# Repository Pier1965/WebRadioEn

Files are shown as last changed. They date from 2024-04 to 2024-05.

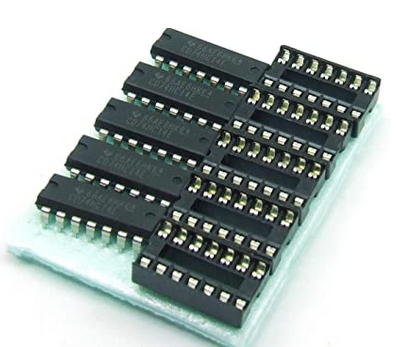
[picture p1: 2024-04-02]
Docs/Bom/img/74HC14.png

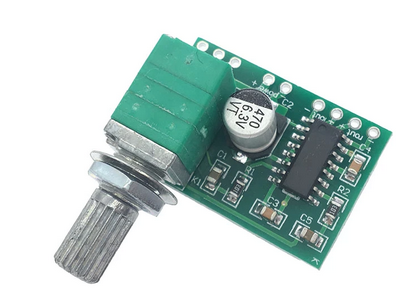
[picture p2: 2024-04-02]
Docs/Bom/img/PAM8432.png

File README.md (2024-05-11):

Esp32 web radio
---------------

This is a esp32 based web radio.
All the hardware requirements, schematics and pinout, can be fount in the Docs subfolders.
All the drawings for a suitable 3D printed case, in openscad format, can be found
in the Docs/drawings directory.

Settings
--------
The following files could/should be altered in order to personalize the compilation
process. This latter can been performed relying on VS code and the Platformio plugin:
- platformio.ini (set the esp32 model);
- include/gpio.h (for different pinout configuration);
- include/define.h (change OLED dimensions and pinout, enable use of NEXTION touch);
- nclude/ir_butt.h (setting the IR remote control);
- include/preproDefine.h (to set debug option);
- include/GlobalVar.h (to set a different ntp server);
- include/GlobalObject.h line 16 (to set the local time zone).

First run
---------
With the working mode switch (clock/radio) in clock position,
at the first start the radio will act as an Access Point with
the name "WebRadioAP". Connect to it and go to the address
192.168.1.4 where SSID and password of the home wifi can be set.
SSID and password can be changed anytime in clock mode pushing
the volumeUp button.

List of radios managing
-----------------------
At the first start a few stations will be available. The list of stations
can be altered by accessing the address of the radio,
readable on the OLED screen by means of a browser.
Stations can be:
- added;
- deleted singularly and in group;
- reordered moving each station in a new position in list;
- swapped in position;
- searched via key word search querying https://www.radio-browser.info/
- the list created can be exported in json format;
- a list can be inported in json format.

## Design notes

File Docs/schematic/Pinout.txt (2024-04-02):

  Wiring:
  ---------------------
  | VS1053  |  ESP32  |
  ---------------------
  |   SCK   |  IO18   |
  |   MISO  |  IO19   |
  |   MOSI  |  IO23   |
  |   XRST  |  EN     |
  |   CS    |  IO5    |
  |   DCS   |  IO0    |
  |   DREQ  |  IO4    |
  |   5V    |  5V     |
  |   GND   |  GND    |
  ---------------------

  ---------------------------
  | JMDO 96C-1 OLED | ESP32 |
  ---------------------------
  | SDA             | 21    |
  | SCL             | 22    |
  | GND             | GND   |
  | 5V              | 5V    |
  ---------------------------

  ---------------------------
  | IR module elegoo | ESP32 |
  ---------------------------
  | G                | GND   |
  | R                | 5V    |
  | Y                | G26   |
  ----------------------------

  ----------------------------
  | Pulsanti         | ESP32  |
  ----------------------------
  | Vol UP           | G32    |
  | Vol Down         | G33    |
  | Next Station     | G13/34 | wroom/wrover - B ttgo
  | Prv Station      | G12    |
  | Radio-Clock Sel  | G36/35 | wroom/wrover - B ttgo
  ----------------------------

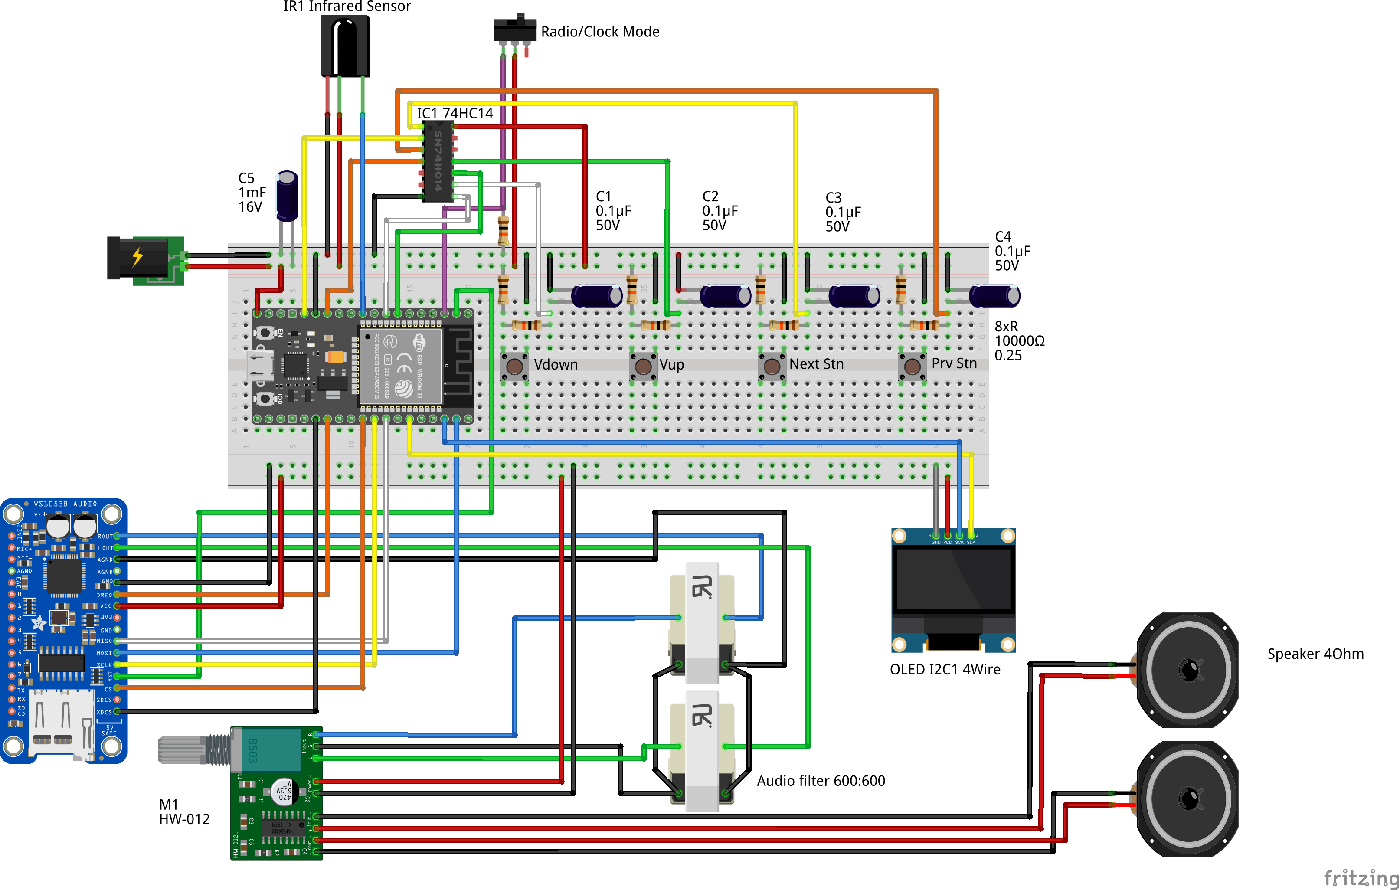
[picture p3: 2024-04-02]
Docs/Bom/img/Schematic.png

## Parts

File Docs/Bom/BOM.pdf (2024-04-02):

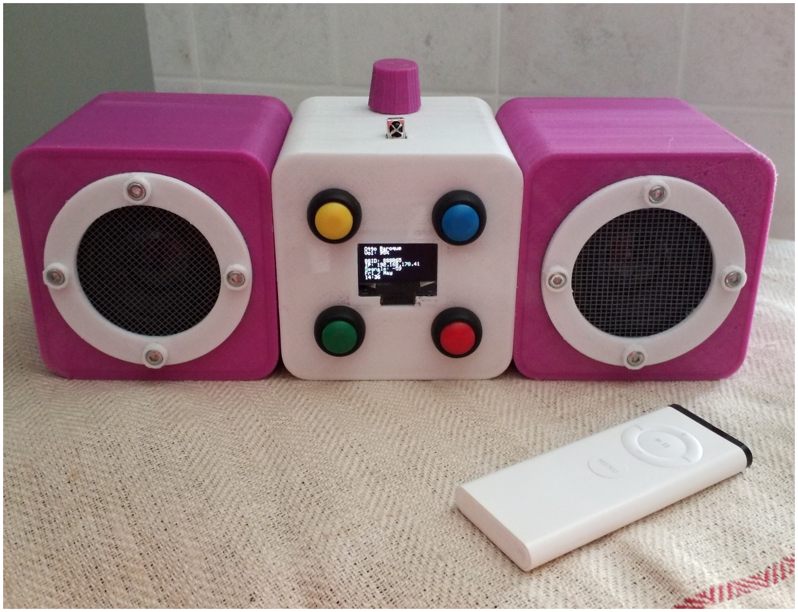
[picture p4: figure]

# N-th Web Radio

# Bill of Materials

Q.ty | Description | Picture | Link

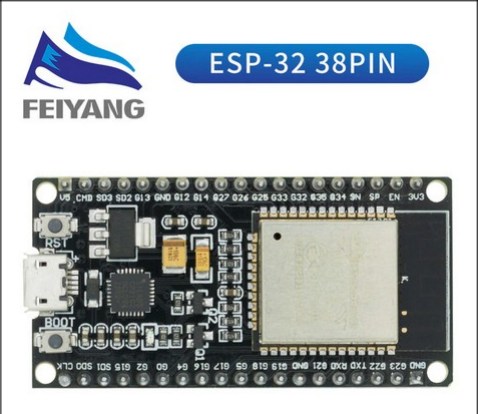
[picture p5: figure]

n.1 | ERP32 Wroom | | ESP32 (https://it.aliexpress.com/item/32864722159.html?spm=a2g0s.9042311.0.0.27424c4dDjW3SZ)

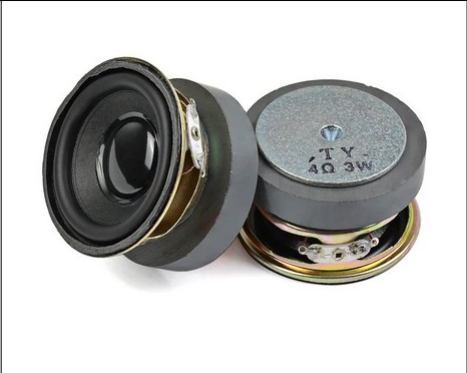
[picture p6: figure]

N.2 | AIYIMA 2 PCS 4ohm 3 W | | Loudspeaker 4Ohm (https://it.aliexpress.com/item/32912123079.html?spm=a2g0s.9042311.0.0.27424c4dL3zYdo)

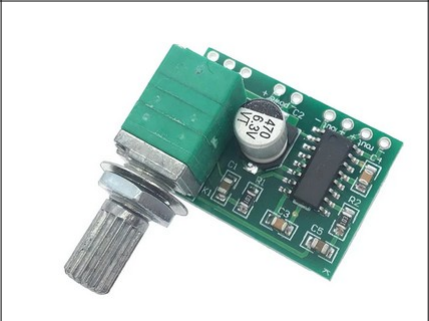
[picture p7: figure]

N.1 | PAM8403 | | Amplifier (https://it.aliexpress.com/item/966217332.html?spm=a2g0s.9042311.0.0.27424c4dr9aevu)

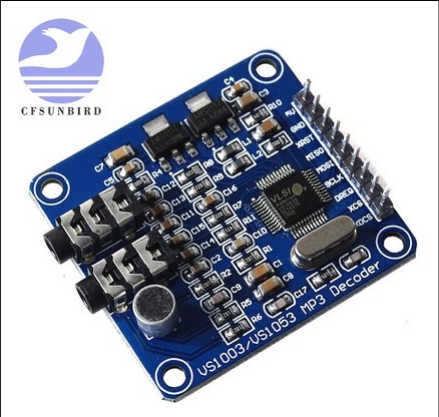
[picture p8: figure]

N.1 | VS1003B VS1053 | | Mp3 chip (https://it.aliexpress.com/item/4001146067436.html?spm=a2g0s.9042311.0.0.27424c4dr9aevu)

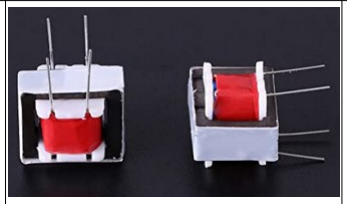
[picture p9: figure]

N.2 | Audio transformer T 1:1 / 600:600 | | Audio filters (https://www.amazon.it/gp/product/B08JCWNKHQ/ref=ppx_yo_dt_b_asin_title_o06_s00?ie=UTF8&psc=1)

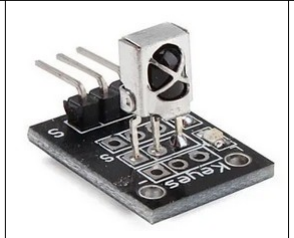
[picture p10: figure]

N.1 | IR Sensor | KY-022 IR (https://it.banggood.com/KY-022-Infrared-IR-Sensor-Receiver-Module-p-916178.html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)

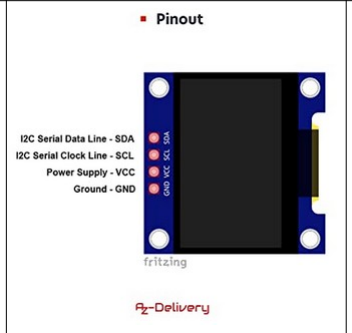
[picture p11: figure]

N.1 | OLED 128x64 4 wire | OLED 1306 (https://www.amazon.it/gp/product/B074N9VLZX/ref=ppx_yo_dt_b_asin_title_o03_s00?ie=UTF8&psc=1)


N.1 | HC74C14 Triggered NOT gate | 74HC14 (https://www.amazon.it/gp/product/B07DT37Y85/ref=ppx_yo_dt_b_asin_title_o07_s00?ie=UTF8&psc=1)


N.1 | Electrolytic capacitor: 1mF x 16V | 1mF Capacitor (https://www.amazon.it/gp/product/B07MNZRBRQ/ref=ppx_yo_dt_b_asin_title_o05_s00?ie=UTF8&psc=1)


N.4 | Electrolytic capacitor: 0.1umF x 16V | 1mF Capacitor (https://www.amazon.it/gp/product/B07MNZRBRQ/ref=ppx_yo_dt_b_asin_title_o05_s00?ie=UTF8&psc=1)


N.9 | Resistor 10KOhm 0.25W | Resistors (https://www.amazon.it/dp/B071Z66XDV?aaxitk=a59ea1286d5f9834aeef6317356b4ac4&hsa_cr_id=2948124570102)


N.4 | Push buttons | Push buttons (https://www.amazon.it/gp/product/B06XCSB9N3/ref=ppx_yo_dt_b_asin_title_o06_s00?ie=UTF8&psc=1)


N.1 | 5.5mm Power supply jack | 5.5 mm Jack (https://hobbyking.com/en_us/2-1mm-5-5mm-dc-chassis-socket-jack-2pc.html?___store=en_us)


N.1 | Switch Radio/Clock mode | Switch (https://www.amazon.it/NATEE-Interruttore-Levetta-Bilanciere-TEN1021/dp/B082B2HCNF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)

# Schematic


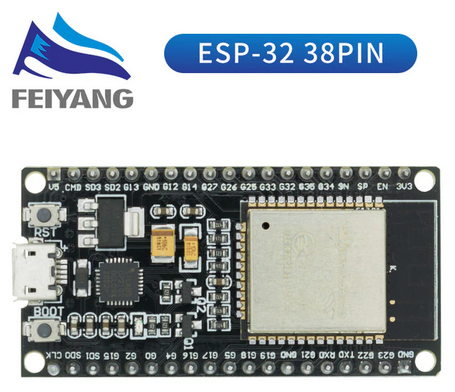
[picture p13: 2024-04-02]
Docs/Bom/img/esp32-wroom.png

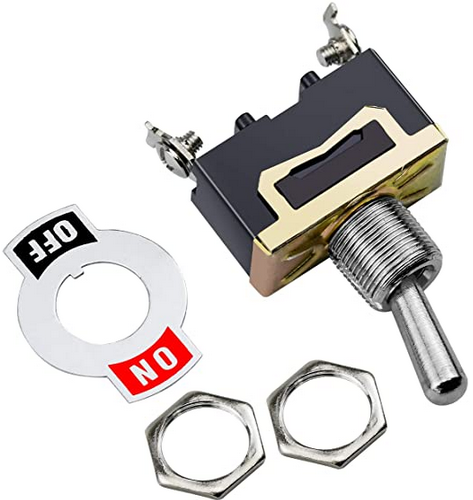
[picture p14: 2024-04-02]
Docs/Bom/img/interruttore.png

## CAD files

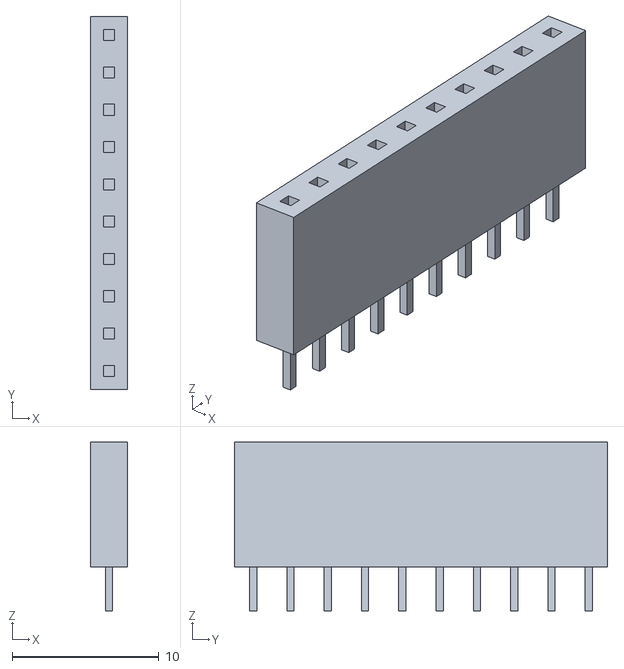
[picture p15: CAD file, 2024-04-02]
Docs/drawings/dupont.stl
2.54 x 25.4 x 11.5

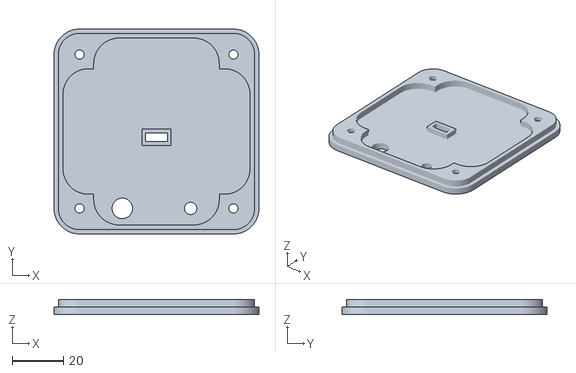
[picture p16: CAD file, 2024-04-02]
Docs/drawings/tappo-case.stl
80.0 x 80.0 x 6.00

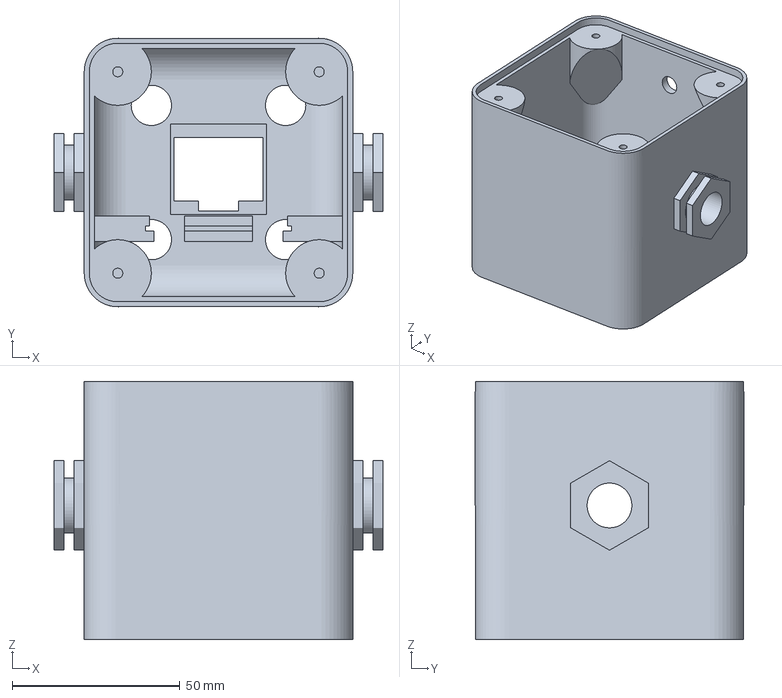
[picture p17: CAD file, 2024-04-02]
Docs/drawings/Gcode/WDI3_case.3mf
98.0 x 80.0 x 77.0 mm

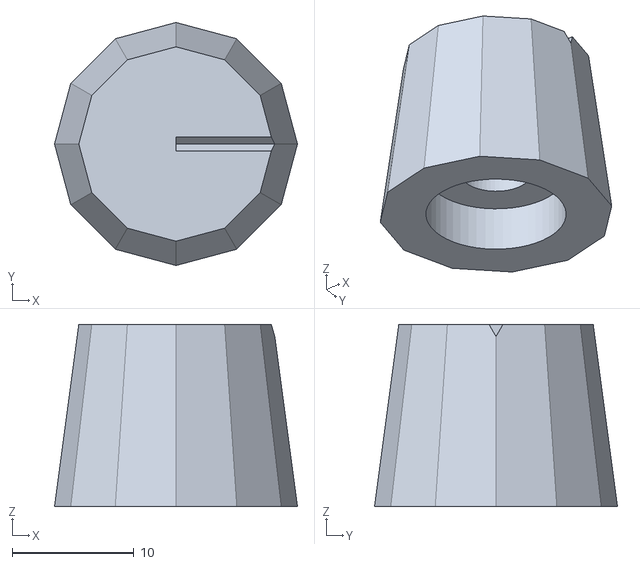
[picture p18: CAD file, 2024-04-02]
Docs/drawings/knob.stl
20.0 x 20.0 x 15.0

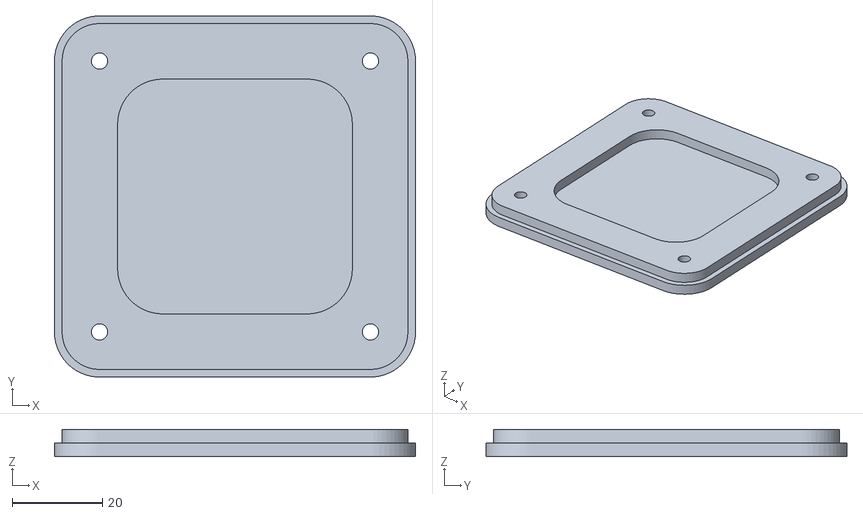
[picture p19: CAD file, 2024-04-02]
Docs/drawings/tappo-cassa.stl
80.0 x 80.0 x 6.00

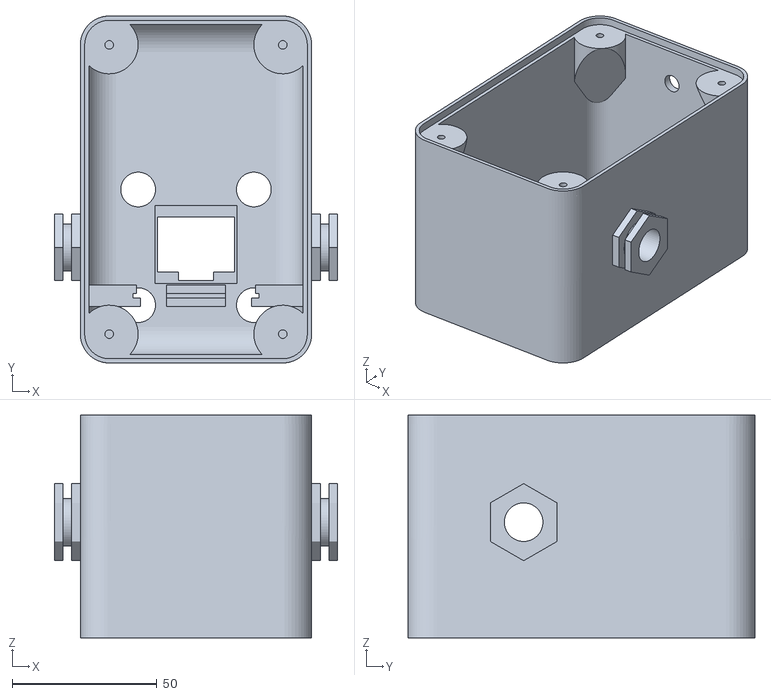
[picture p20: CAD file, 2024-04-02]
Docs/drawings/case-large.stl
98.0 x 120.0 x 77.0

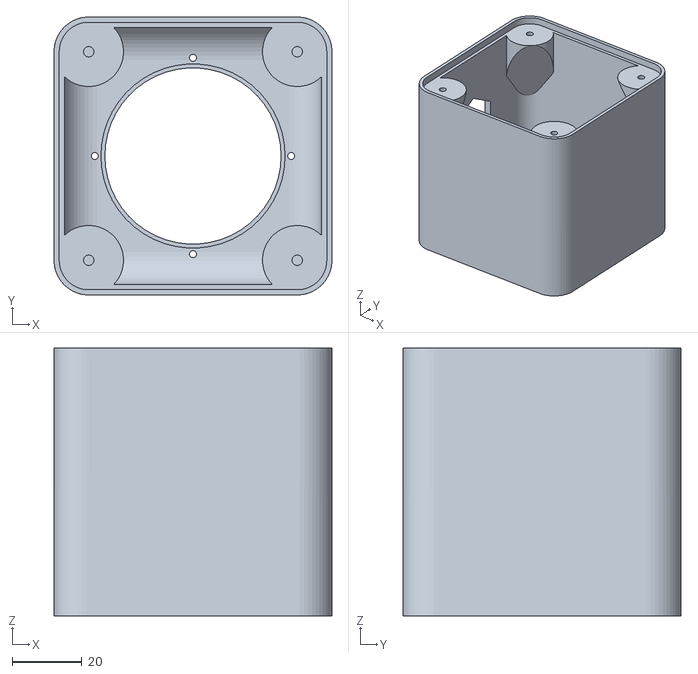
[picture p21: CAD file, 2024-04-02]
Docs/drawings/cassa.stl
80.0 x 80.0 x 77.0

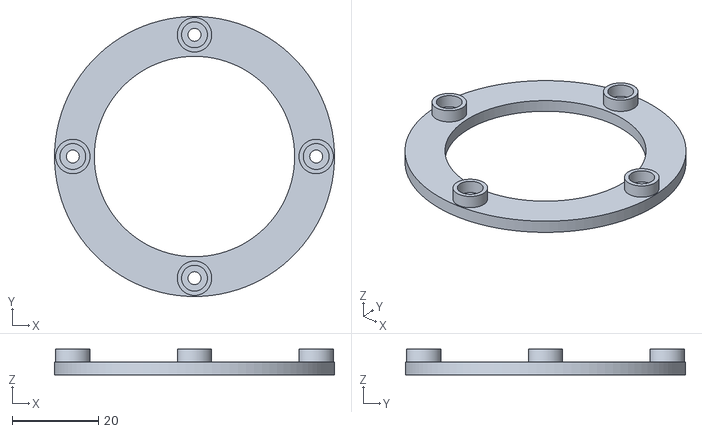
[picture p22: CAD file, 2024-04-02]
Docs/drawings/anello.stl
65.0 x 65.0 x 5.99

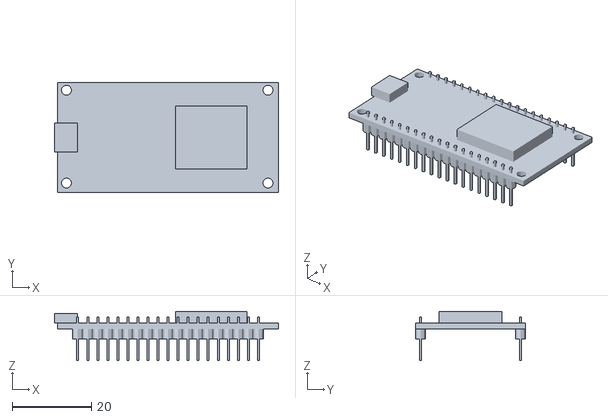
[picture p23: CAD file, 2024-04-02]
Docs/drawings/esp32_wroom.stl
56.7 x 27.9 x 12.5

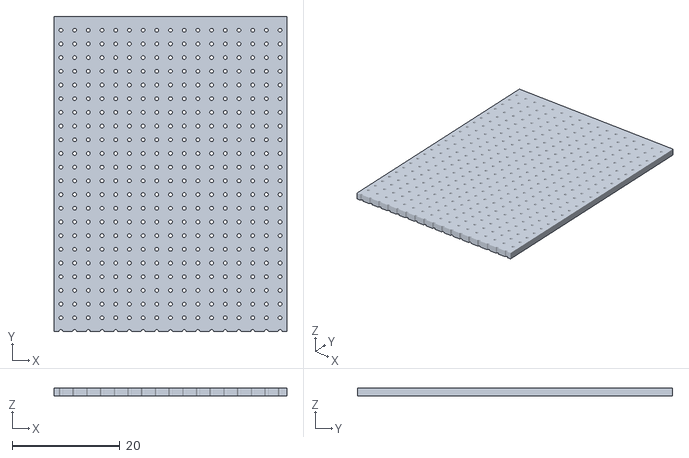
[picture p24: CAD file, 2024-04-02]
Docs/drawings/millefori.stl
43.2 x 58.4 x 1.50

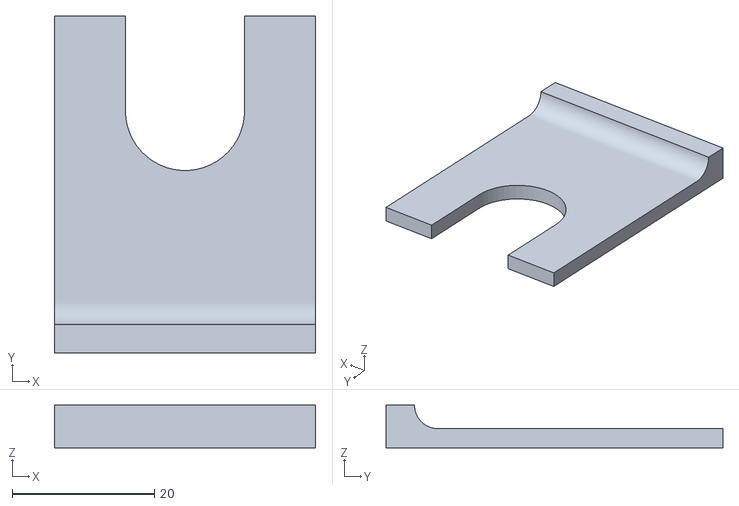
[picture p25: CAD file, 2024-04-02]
Docs/drawings/forchetta.stl
36.7 x 47.3 x 6.00

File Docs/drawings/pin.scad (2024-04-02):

//pin
include<dimensioni.h>
module pin(){
    union(){
        translate([0,0,-lpin2])
            linear_extrude(lpin)
                square(wpin,true);
        // base pin
        cylinder($fn=8,h=hbp,r=rbp);
    }
}
//pin();

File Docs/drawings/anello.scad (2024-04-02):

// Anello di fissaggio retina di protezione
include<dimensioni.h>
module anello(){
$fn=100;
difference(){
    union(){
cylinder(h=Ha, r=Rea);
    translate([Rffa,0,Ha-0.01])
    cylinder(h=Hsv,r=Rsv+1);
     translate([0,Rffa,Ha-0.01])
    cylinder(h=Hsv,r=Rsv+1);
         translate([0,-Rffa,Ha-0.01])
    cylinder(h=Hsv,r=Rsv+1);
        translate([-Rffa,0,Ha-0.01])
    cylinder(h=Hsv,r=Rsv+1);
    }
cylinder(h=Ha*3,r=Ria, center=true);
    //Fori passaggio viti M3
    translate([Rffa,0,-1])
    cylinder(h=Ha*3,r=rffaa);
     translate([-Rffa,0,-1])
    cylinder(h=Ha*3,r=rffaa);
    translate([0,Rffa,-1])
    cylinder(h=Ha*3,r=rffaa);
     translate([0,-Rffa,-1])
    cylinder(h=Ha*3,r=rffaa);
    //scasso retina
    translate([0,0,-0.05])
    cylinder(h=0.2,r=rffaa+Rffa+1);
    //scassi teste viti
    translate([Rffa,0,Ha])
    cylinder(h=Hsv,r=Rsv);
    translate([-Rffa,0,Ha])
    cylinder(h=Hsv,r=Rsv);
     translate([0,Rffa,Ha])
    cylinder(h=Hsv,r=Rsv);
    translate([0,-Rffa,Ha])
    cylinder(h=Hsv,r=Rsv);
}
}
anello();

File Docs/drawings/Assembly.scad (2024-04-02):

//include <case.scad>
include<case_small.scad>
include <cassa.scad>
include<forchetta.scad>
include<tappo-case.scad>
include<esp32_wroom.scad>
include<millefori.scad>
include<dupont.scad>
include<anello.scad>

// Case radio
color("white")
    case();

// Casse laterali
translate([L,0,0])
    color("magenta")
    cassa();
    
translate([0,L,0])
    rotate([0,0,180])
    color("magenta")
        cassa();
  
 color("green")
 translate([S+L,wf/2+L/2,L-2*S])
 rotate([90+180,0,90+180])
 forchetta();
 
 color("green")
 translate([-S,-wf/2+L/2,L-2*S])
 rotate([90+180,0,90])
 forchetta();
 

  //Blocco esp32, millefori con dupont
 translate([0,S+7*S,0]){ 
 color("green")
    translate([w/2+L/2,hdup+hbp,lmf+S+5*passo])
        rotate([-90,90,0])
            esp32();
 
 translate([L/2-wmf/2,0,S+5*passo])
    color("red")
        rotate([90,0,0])
            basettamf();

color("yellow"){
    translate([L/2-dpw/2+dpw+2*passo,0,lmf+S-2*passo+5*passo])
        rotate([-90,0,0])
            dupont(19); 
    translate([L/2-dpw/2-2*passo,0,lmf+S-2*passo+5*passo])
        rotate([-90,0,0])
            dupont(19);
    
    translate([L/2-dpw/2+dpw,0,lmf+S-2*passo+5*passo])
        rotate([-90,0,0])
            dupont(19); 
    translate([L/2-dpw/2,0,lmf+S-2*passo+5*passo])
        rotate([-90,0,0])
            dupont(19);
}
}
 /*
 color("blue",1)
 translate([L,0,L])
 rotate([0,180,0])
 tappocase();
 */
// Anello retina protezione
color("white")
translate([-L/2,L/2,0])
rotate([180,0,0])
anello();

color("white")
translate([3*L/2,L/2,0])
rotate([180,0,0])
anello();

 

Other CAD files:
Docs/drawings/Gcode/WDI3_forchetta.3mf
Docs/drawings/Gcode/WDI3_cassa.3mf
Docs/drawings/case.stl
Docs/drawings/case_small.stl
Docs/drawings/case-0.0.scad
Docs/drawings/case.scad
Docs/drawings/case_small.scad
Docs/drawings/cassa-0.0.scad
Docs/drawings/cassa.scad
Docs/drawings/dupont.scad
Docs/drawings/esp32_wroom.scad
Docs/drawings/esp8266mod.scad
Docs/drawings/forchetta.scad
Docs/drawings/knob.scad
Docs/drawings/millefori.scad
Docs/drawings/tappo-case.scad
Docs/drawings/tappo-cassa.scad

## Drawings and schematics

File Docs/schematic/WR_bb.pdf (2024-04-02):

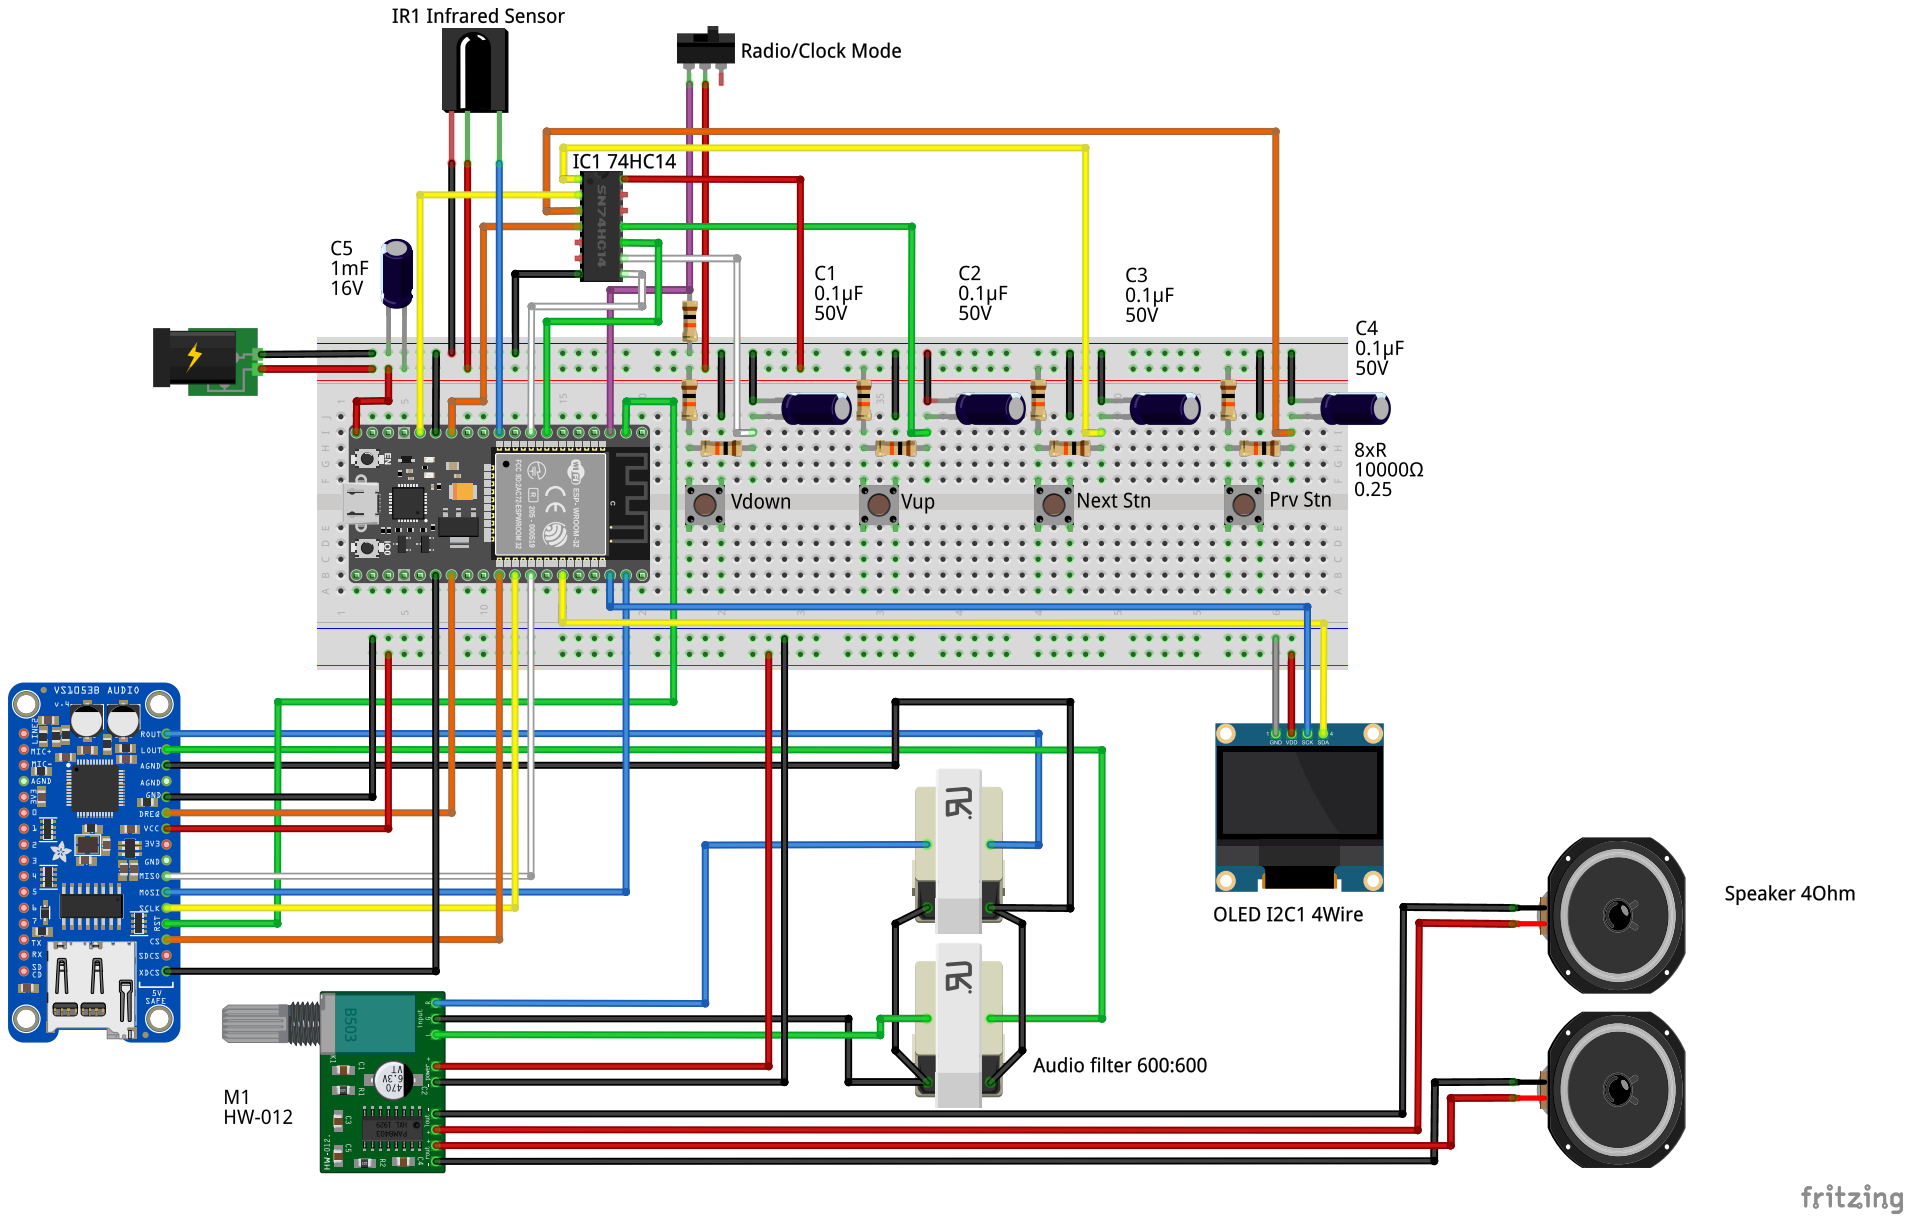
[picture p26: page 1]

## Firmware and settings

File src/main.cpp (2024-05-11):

/*
  Web radio con ESP32

  Pierpaolo Garofalo - http://pier.unirc.eu
  Licensed under GNU GPL v3
 //================================================================================= 
27/04/2021
1) Gestisce immissione cambio stazioni e volume tramite pulsanti HW con debouncing SW e HW  (v)
2) Memorizza Stazion e Volume in eeprom                                                     (v)
Otto baroque si sente a volte bene e a volte con singhiozzo a buffer 64, con 32 pare liscio
28/04/2021
3) Interfaccia OLED con info rete e canale                                                  (v)
4) Telecomando IR di vari tipi per cambio stazione e volume                                 (v)
5) Orario e data in OLED                                                                    (v)
01/05/2021
6) Modalità radio oppure orologio
08/05/21
7) Pare risolta questione BBC #208 https://www.youtube.com/watch?v=aMS4XwEr8s0&t=51s 
  Nei commenti di random sporadic projects
  Fine 2023 BBC è passata a HSL :-(
8) Aggiunto digit a orari inferiori alle 9
09/05/2021
9) Modificata gestione ora. Se l'orario è stato ottenuto in avvio da NTP non usiamo di nuovo la connessione alla rete
10) Multiwifi per connettersi a piu reti wifi e riconnessione corretta nel caso si perda il collegamento
10/05/21
11) Quando si cambia modalità da Clock a Radio riconnettere wifi e stazione e viceversa
12/05/2021
12) Implementato ring buffer per risolvere Otto Baroque a 320kbps che balbetta... pare funzionare
04/05/2022
    Ringbuffer e abbandonato sia con libreria originale (mio metodo) che librerie di Cellies (disabilitare PSRAM)
    a causa dei continui buffer underrun con Komsomolskaia Pravda 
    Gennaio 2024 
13) Aggiunta gestione tasti da 0-9 IR con telecomandi che li prevedono (Elegoo)
14) Aggiunta gestione SSID e passwordtramite portale AP 192.168.4.1: in modalità clock 
    schiacciare il pulsante VolUp e collegarsi alla rete WebRadioAP e impostare SSID e password di rete
    08/02/2024
15) Eliminato l'hard code di SSID e Password: tolto multiwifi e messo wifimanager
    09/02/2024
16) OLED, IR, Tasti, e modalità di funz OK
    6/02/2024
17) Correzione aggiornamento della data ora locale che non prevedeva il settaggio LOCALE
18) Passaggio alla libreria 
      baldram/ESP_VS1053_Library 
      celliesprojects/ESP32_VS1053_Stream@^2.0.6 -> La RAI si risente con queste ... boh
      con cellies però il ring buffer continua a dare underrun con Radio Komsomolskaia
    Eliminato hard coding delle stazioni radio:
    Gestione inserimento stazioni via html: webserver e websocket
    Gestione della lista di radio con funzioni aggiungi, sposta ecc
    Passaggio a platformio con board wrover e wroom
    15/03/2024 
19) Gestione tasti telecomando per doppia cifra 
    21/03/2024
20) Gestione visualizzazione html ottimale per dispositivi
    17/03/2024 (parziale)
21) Gestione ricerca radio con api Radio-Browser
    https://www.radio-browser.info/
    21/03/2024
22) Aggiunto telecomando IR TANIX smart TV, e KC-808
    22/03/2024
23) Aggiunta possibilità di impostare stazione e volume da browser
    via lista comandi a tendina
    27/03/2024
24) Aggiunta la possibilità di esportare la lista delle radio in formato Json
    ListaRadio.json
    28/03/2024
25) Aggiunta la possibilità di importare la lista delle radio in formato Json
    Per gestire file di dimensione maggiore di 1346b, in WebServer.h
    riga 38)  #define HTTP_DOWNLOAD_UNIT_SIZE 3*1436
    riga 41)  #define HTTP_UPLOAD_BUFLEN 3*1436
    01/04/2024
25)	Aggiunto schermo touch NEXTION NX4832T035_011
	25/04/2024
    Da fare:
    Aggiungere verifica sulla coerenza dei dati Pos.1 Pos.2 immessi per la modifica
    della lista di radio.
    Evitare che all'upload della lista di radio si passi alla
    pagina /upload
    Impostare schermo OLED con caratteri grandi indicazione volume e stazione
    durante cambio stazione e volume
    Aggiungere tasti Mute e Clock/Radio mode da telecomando
    Aggiungere OLED a colori 
    xx/xx/xx
//=================================================================================
*/
#include "preproDefine.h"
#include "define.h"
#include "GlobalVar.h"
#include "includeLib.h"
#include "GlobalObject.h"
#include "includeFun.h"
//=================================================================================
void setup(){
  #ifdef SPION
    Serial.begin(115200);
  #endif
  // Config pin del selettore modalità di funzionamento
  confSelector();
  //Setup OLED : Strano... se messo dopo setupInt fa incartare l'ascolto
  initSCR();
  // Inizializzazione del NEXTION se usato
  #ifdef NEXTOUCH
    nexExists = initNex();
  #endif
  // Avvio del wifi. Se non c'è una configurazione ESSD e PW avvia AP su 192.168.1.4
  // per immettere i valori di rete e ip della radio via browser
  // Se non vengono immessi attende 120 sec, va in timeout e si riavvia.
  //=================================================================================
  if(!wifi_connect()){
    DEBUG_PRINTLN("Non Connesso...");  
    DEBUG_PRINTLN("ESP si riavvia...");
    updateAPSCR(TIMEOUT);
    delay(5000);
    ESP.restart();
  }
  // Inizializzazione del file system SPIFF
  //=================================================================================
  if(!SPIFFS.begin(true)){
    DEBUG_PRINTLN("File system SPIFF non montato... riavvio");
    delay(5000);
    ESP.restart();    
  } else{
    DEBUG_PRINTLN("File system SPIFF montato!!!!!!!");   
  }
  // Inizializzazione file delle radio in un oggetto json
  //=================================================================================
  if(!initRadioFileList()){
    DEBUG_PRINTLN("File radio non inizializzato... riavvio");
    delay(5000);
    ESP.restart();
  }
  // Inizializzazione e gestione del web server 
  //Invio della pagina principale che accetta richieste GET con i campi di input
  //=================================================================================
  startServer();
  DEBUG_PRINTLN("HTTP server e webSocket started");
  // Recupero dell'ora dal server NTP
   //=================================================================================
  initTime();
  restoreEeprom();
  // Inizializzo il decoder Mp3
  //=================================================================================
  SPI.begin();
  SPI.setHwCs(true);
  SPI.begin(SPI_CLK_PIN, SPI_MISO_PIN, SPI_MOSI_PIN);  /* start SPI before starting decoder */
  if (!stream.startDecoder(VS1053_CS, VS1053_DCS, VS1053_DREQ)){
    DEBUG_PRINTLN("Cannot start decoder mp3");
     while (1) delay(100);
  }
  if(!stream.isChipConnected())
  {
      DEBUG_PRINTLN("Decoder not connected");
      while (1) delay(100);
  };
  DEBUG_PRINTLN("Decoder running");
  delay(100);
  // Setup delle routine di interrupt per i tasti stazone e volume
  //=================================================================================
  setupInt();
  //Inizializza sensore IR
  //=================================================================================
  StartIR();
  delay(100);
  /*
      DEBUG_PRINT("codec: ");
      DEBUG_PRINTLN(stream.currentCodec());
      DEBUG_PRINT("bitrate: ");
      DEBUG_PRINT(stream.bitrate());
      DEBUG_PRINTLN("kbps");
  */
  //
  // Se la levetta è in modalità orologio spegni il wifi
  //=================================================================================
  WMode = workingMode();
  DEBUG_PRINT("WMode = ");
  DEBUG_PRINTDEC(WMode);
  DEBUG_PRINTLN("");
  if(!WMode){
    DEBUG_PRINTLN("Disconnessione e spegnimento WiFi...");
    WiFi.disconnect(true);
    WiFi.mode(WIFI_OFF);
    #ifdef OLEDJMDO
      updateTimeScr();
    #endif
    #ifdef NEXTOUCH
      updateTimeScr_nex();
    #endif
  }else{
    stream.setVolume(VOLUME);
    JsonObject record = radioRecords[STATION].as<JsonObject>();
    if(record.containsKey(POS2)){
      url = record[POS2];
    }
    stream.connecttohost(url);
      DEBUG_PRINT("codec: ");
      DEBUG_PRINTLN(stream.currentCodec());
      DEBUG_PRINT("bitrate: ");
      DEBUG_PRINT(stream.bitrate());
      DEBUG_PRINTLN("kbps");
      #ifdef OLEDJMDO
        updateSCR();
      #endif
      #ifdef NEXTOUCH
        updateSCR_nex();
      #endif
  }
  oldWMode=WMode;
}
// Loop
//=================================================================================
void loop() {
  server.handleClient();
  webSocket.loop();
  WMode = digitalRead(RCSelector);
  // Gestione del cambio della modalità di funzionamento
  // RADIO <-> CLOCK
  //=================================================================================
  if(oldWMode != WMode){
    DEBUG_PRINTLN("Modalita funz cambiata");
    oldWMode = WMode;
    // CLOCK -> RADIO
    //=================================================================================
    if(WMode){
      DEBUG_PRINTLN("Modalita radio");
      // Riaccendo il WIFI
      if(!wifi_connect()){
        DEBUG_PRINTLN("Non Connesso...");  
        DEBUG_PRINTLN("ESP si riavvia...");
        delay(100);
        updateAPSCR(TIMEOUT);
        delay(5000);
        ESP.restart();
      }
      delay(100);
      // Ripristino volume e stazione
      stream.setVolume(VOLUME);
      record = radioRecords[STATION].as<JsonObject>();
      if(record.containsKey(POS2)){
        url = record[POS2];
      }
      // Tentativo di connessione alla stazione radio
      while(!stream.connecttohost(url)){
        // Da fare: qui devo gestire il caso di mancata connessione a TUTTE le radio
        // in elenco... es i++ ad ogni ciclo fino a NR e poi riavviare?
        DEBUG_PRINTLN("Host non connesso");
        DEBUG_PRINTLN("Cambio stazione");
        delay(1000);
        // Qui gestisco la mancata connessione
        // vedo se l'ultimo cambio di stazione è stato in avanti
        // o in dietro e così cerco nella stessa direzione
        if(nxtButton == 1){
          STATION < (NR-1) ? STATION++ : STATION = 0;
        }else{
          STATION > 0 ? STATION-- : STATION = NR-1;
        }
        updateEeprom();
        record = radioRecords[STATION].as<JsonObject>();
        if(record.containsKey(POS2)){
          url = record[POS2];
        }
        DEBUG_PRINTDEC(STATION);
        DEBUG_PRINTLN();
        #ifdef OLEDJMDO
          updateSCR();
        #endif
        #ifdef NEXTOUCH
          updateSCR_nex();
        #endif
      }
      delay(500);
      #ifdef OLEDJMDO
        updateSCR();
      #endif
      #ifdef NEXTOUCH
        updateSCR_nex();
      #endif
    }else{
      // RADIO -> CLOCK
      //=================================================================================
      // Se si è passati in modalità CLOCK spengo il wifi
      // e cancello l'istanza dello stream
      DEBUG_PRINTLN("Disconnessione e spegnimento WiFi...");
      stream.stopSong();
      WiFi.disconnect(true);
      WiFi.mode(WIFI_OFF);
      #ifdef OLEDJMDO
        updateTimeScr();
      #endif
      #ifdef NEXTOUCH
        updateTimeScr_nex();
      #endif
    }
  }
  //=================================================================================
  // Gestione funzionamento in mdalità RADIO
  if(WMode){
    jsonString = "";
    serializeJson(jsonDoc_tx, jsonString);
    while(digitalRead(RCSelector)){
      server.handleClient();
      webSocket.loop();
      // Rimedio al fatto che non riesco a far caricare la lista al caricamento
      // della pagina
      currentWsMillis = millis();
      if(currentWsMillis - startWsMillis > updateWsTime){
        webSocket.broadcastTXT(jsonString);
        startWsMillis = currentWsMillis;
      }
      // Gestione radio in modalità playing
      stream.loop();
      delay(5);
      // check dei comandi NEXTION
      #ifdef NEXTOUCH
        if(nexExists)
          nexLoop(nex_list);
      #endif
      //Check dei tasti e dei comandi IR
      checkIR();
      switch (checkButtons()) {
        case STNCH:
          stream.stopSong();
          delay(1000);
          record = radioRecords[STATION].as<JsonObject>();
          if(record.containsKey(POS2)){
            url = record[POS2];
            DEBUG_PRINTLN(url);
          }
          // Gestione eventuale mancata connessione
          // e cambio del canale. Da gestire mancata connessione a tutti
          // i canali
          while(!stream.connecttohost(url)){
            // L'host non è disponibile... cambio canale
            DEBUG_PRINTLN("Host non connesso");
            delay(1000);
            // Qui gestire la mancata connessione
            if(nxtButton == 1){
              STATION < (NR-1) ? STATION++ : STATION = 0;
            }else{
              STATION > 0 ? STATION-- : STATION = NR-1;
            }
            updateEeprom();
            record = radioRecords[STATION].as<JsonObject>();
            if(record.containsKey(POS2)){
              url = record[POS2];
            }
          }
          DEBUG_PRINTDEC(STATION);
          DEBUG_PRINTLN();
          #ifdef OLEDJMDO
            updateSCR();
          #endif
          #ifdef NEXTOUCH
            updateSCR_nex();
          #endif
        break;
        case VOLCH:
          stream.setVolume(VOLUME);
          DEBUG_PRINTDEC(VOLUME);
          DEBUG_PRINTLN();
          #ifdef OLEDJMDO
            updateSCR();
          #endif
          #ifdef NEXTOUCH
            updateSCR_nex();
          #endif
        break;
      }
      if(checkTime()){
        #ifdef OLEDJMDO
          updateSCR();
        #endif
        #ifdef NEXTOUCH
          updateSCR_nex();
        #endif
      }
    }
  }else{
    //=================================================================================
    // Funzionamento in modalità CLOCK
    DEBUG_PRINTLN("Orologio");
    while(!digitalRead(RCSelector)){
      // Gestione radio in modalità orologio
      if(checkTime()){
        #ifdef OLEDJMDO
        updateTimeScr();
      #endif
      #ifdef NEXTOUCH
        updateTimeScr_nex();
      #endif
      }
      // In modalità CLOCK schiacciando Volume Up si richiede
      // l'avvio del portale 192.168.4.1 per la gestione
      // del SSID e PW wifi
      if (digitalRead(volumeUp) == HIGH) {
        updateAPSCR(TIMEOUT);
        delay(100);
        setSsidPw();
      }
    }
  }
}

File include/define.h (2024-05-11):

///////////////////////////////////////////////////
// Rilascio versione software
#define RelDate "Marzo 2024"
// incremento volume click
#define DVOL 5
// Valori ritornati da cambio stazione o volume
#define STNCH 1
#define VOLCH 2
// gestione valori in flash eeprom
// memorizziamo STATION e VOLUME
#define EEPROM_SIZE 2
// Oled display JMDO 96C-1 OLED
#define OLEDJMDO
#ifdef OLEDJMDO
	#define SCREEN_WIDTH 128 // OLED display width, in pixels
	#define SCREEN_HEIGHT 64 // OLED display height, in pixels
	// Declaration for an SSD1306 display connected to I2C (SDA, SCL pins)
	// The pins for I2C are defined by the Wire-library.
	// On an arduino UNO:       A4(SDA), A5(SCL)
	// On an arduino MEGA 2560: 20(SDA), 21(SCL)
	// On an arduino LEONARDO:   2(SDA),  3(SCL), ...
	// Esp32:   SDA -> G21, SCL -> G22
	#define OLED_RESET     4 // Reset pin # (or -1 if sharing Arduino reset pin)
	#define SCREEN_ADDRESS 0x3C ///< See datasheet for Address; 0x3D for 128x64, 0x3C for 128x32
#endif
#ifdef ARDUINO_ARCH_ESP32
	#define VS1053_CS     5
	#define VS1053_DCS    0
	#define VS1053_DREQ   4
	#define SPI_CLK_PIN 18
	#define SPI_MISO_PIN 19
	#define SPI_MOSI_PIN 23
#endif
// Upate time screen in modalità clocl
#define UPDATETMRSCR 5000
// Timeout access point e connessione
#define TIMEOUT 120
// Codifica tasti di telecomandi a infrarossi
#include "ir_butt.h"
// Campi del file info radio
#define POS1 "pos" 		// "field1"
#define POS2 "stream" 	// "field2"
#define POS3 "nome" 	// "field3"
#define POS4 "genere"	// "field4"
// Gestione NEXTION
#define NEXTOUCH
